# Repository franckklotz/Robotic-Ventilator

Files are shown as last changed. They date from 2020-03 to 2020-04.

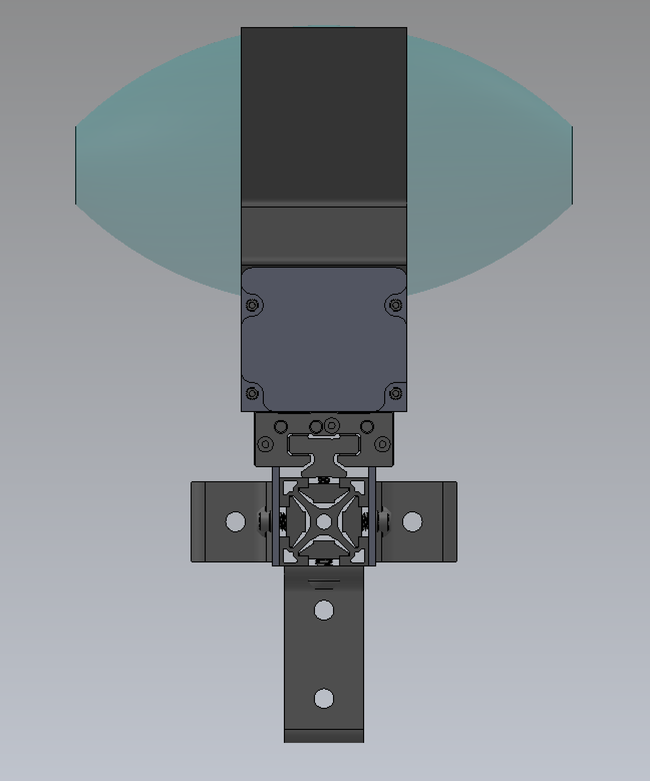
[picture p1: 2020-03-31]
3D rendering/Capture d’écran, le 2020-03-31 à 14.56.15.png

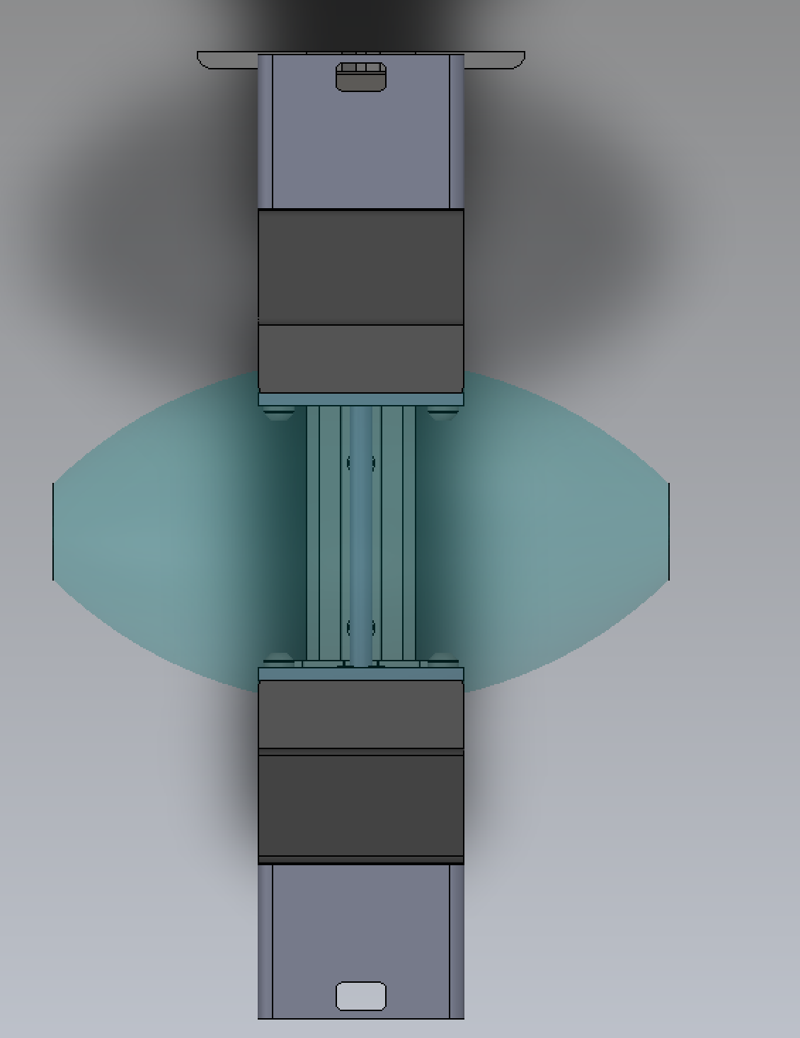
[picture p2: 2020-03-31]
3D rendering/Capture d’écran, le 2020-03-31 à 14.56.59.png

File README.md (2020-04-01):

# Project overview

Hello,

with key people in robotics design and Software development, a MD, and a MD Student, we decided to work on a Ventilator since the Covid-19 crisis.

Since we worked together in multiple indutrial robotic project, we called it Robotic repirator team.

We also participate to the https://www.agorize.com/en/challenges/code-life-challenge?lang=en as Robotic Team. this was a challenge to design a ventilator in a few days .

After few idea, we decided tu use an existing Manual Ventilator, AMBU ( see web site ) and control the flow using a stepper motor to precisely control air flow, volume, cylce per minute. The design can be adapted to similar AMBU compatible manual ventilator to "automate" the process of ventilating.

Thanks to Paulo Arruda and Patrick Schmitt to have "worked" some late night on brainstorming this idea / concept.

unfortunately, we could not get all parts to have a working prototype as per 31 march 2020, so we decided to share openly our idea so we can continu to build and improve around the community.

The Store Closed aroud us ( Montreal, Canada ), and delivery was jumping out of range for us to have a prototype for the 31 march 2020.

So please feel free to get inspired from this proposal and do not hesitate to improve.

do not hesitate to contact us via email for any specific questions.

# Specification

the specification are the folowing :

Pressure control up to 40 cmH2O, expiration pressure up to 25 cmH2O

Respiration ratio from 6 to 40 breath per minute

Adjustable inspiratiory time I:E ration

FiO2 from 21 to 100 % in 10 % increase 

Trigger time and or patient 

Connect to standard mask 

Dual Circuit with non rebreathing valve ( Y patient ) 

humidity and temperature not controlled in our design

O2 read out not in our design 

O2 sensor are very expensive and "impossible to find " @ end of march 2020

# Concept

concept 1  : ML, F and I:E adjustement via software, PEEP mechanical valve

Concept 1a : ML, F and I:E adjustement via software, PEEP mechanical valve, O2 adjustement based on template based on ML/F to adjust O2 volume. ( hospital have valve to adjust flow )

Concept 2  : ML, F and I:E adjustement via software, PEEP mechanical valve, but O2 adjustement via software using electrovalve that will be pulsed based on PWM in order ro mix Air / O2 ratio.

Concept 3  : ML, F and I:E adjustement via software, PEEP mechanical valve, but O2 adjustement via software using electrovalve that will be pulsed based on PWM in order ro mix Air / O2 ratio, and PEEP adjustement on a exhaust chamber based on solenoid valve to exhaust. Safety valve needs to be of course implemented.

please see document pdf for high level concept.

# Mechanical parts

The complete 3D parts and assembly is available in the specific folder. The different Ambu clone may have different dimentions but our intent is to design the claws in such way it will fit the different models destinated to support adults.
It was designed with Solidworks.

you can download a free viewer, edrawing to see the design.

the free viewer will allow you to hide parts ( like cover ) or make some parts transparent, and of course zoom in out, rotate and basic navigation around the mechanical design.

please open the AUTOMATIC AMBU ACTUATOR SYSTEM.SLDASM file to see the assembly.

PARTS :

All parts starting with a number, are https://www.mcmaster.com/ parts. You can oder parts directly from them or find equivalent parts.

Part 3D printed start with a 3D-xxxx. We have access to a 3D printer using ONYX plastic.

the main component is the stepper motor from https://www.pololu.com/product/2689 , this one is provided with the screw ( selected in design for speed of delivery reason ) but you could buy the same motor and adapt your own screw with this motor https://www.pololu.com/product/2267

the motor is sized for 60 respiration per minute, see the calculation excel for sizing.

# Electronic parts

the electronic is designed to have a main microprocessor, based on arduino or particle.io.

Arduino is well available, but the particle board have the capacity to update remotely. ( a plus during development, but a risk once running with real patient ).

the arduino selected was https://www.pololu.com/product/2188

The microprocessor board drives a 4988 stepper motor driver https://www.pololu.com/product/1182 that is controlled usind 2 pin, direction, and pulse for "speed" . This pulse needs to be managed to reach setup speed from medic team, and can also be managed to have "S" curve for inspiration and expiration.

of course, stepper motor needs to have a "zero" this could be achieved by "returning" the motor to zero and have it "mechanically" stopped, or adding a sensor for position zero and monitor this position "zero" for each positive pressure to patient. The flexibility can only by achieved using a Stepper motor.

To improve a little bit more the system, and to have the pressure setup, we wanted to use Athmospheric pressure monitor based on the bosch 280 https://www.adafruit.com/product/2652 . this will allow us to compare ambiant pressure with pressure to AMBU exhaust and manage the stepper motor accordingly, using a PID loop . ( also, with bypass to ensure minimum respiration setup by DRs )

These sensors would have beed used in the output of AMBU, the return from patient to monitor the PEEP pressure ( from 5 to 20 as standard PEEP pressure ), even if we wanted to use existing PEEP valve from AMBU.

This Pressure sensor was also used to monitor patient respiration, in order to do "Assisted Ventilation", and of course have a software to ensure minimum respiration per minute as per standard ventilator.

The precison expected using BOSCH 280 athmospherique sensor was, based on the position in the curve , from 5 to 10 %, that was the acceptable precision range for the challenge.

Once we will get all sensors, we will also test and validate theorie.

Off course, these sensor do not meet the "cleaning" requirement, but this could be changed, and we will mount them in a remote small chanber connected to the main "chambers" to avoid contamination, but this is not ideal.

# Other electric parts

Of course we need to have a power-supply 120-240 to 12 Volts, a Battery charger to charge a battery and keep electricity for 3 hours as per requirement, but this is more "off the shelf " equipment.

We need to finalize electric consumption to size battery.

We should also add Bright LED light and Buzzer to "alarm" medical team .

Again, this is considered standard equipment, from multiple vendor and we did not concentrate theses points.

# UI / UX interface 

to have a User Experience, User Interface able to replicate what the medical team is used, we selected 2 option. 

1 - using a 7.00 inch touch screen
2 - using a smaller 3.2 inch touch screen to save cost and have more availability 

the 7.00 screen is https://www.robotshop.com/ca/fr/affichage-lcd-tactile-7-nextion-hmi.html from Nextion

the 3.20 screen is https://www.robotshop.com/ca/fr/affichage-lcd-tactile-hmi-32-nextion.html also from Nextion

this system is for rapid deveolpement and provide a free "HMI" intreface, and also all code to interface to Arduino and other microprocessor board.

you can download the software to design HMI from nextion at https://nextion.tech/

there is also a cheaper version from China, but not available outside of China.

The 7.00 inch screen is able to draw curve, so we will be able to replicate UI used in actual Ventilator.

# Final case / Box

final concept including a complex box and support for the HMI LCD screen is not finalized, and need to be completed.

this was not our top priority and is "easy" to do once all tests are done.

# Software 

Software wa in a few steps, of course we started with a POC, proof of concept, and evolve to a pre-releae.

- POC : control motor based on "parameter from console" Volume is controlled by Servo 
- STEP 01 : ensure sensor "zero" is activated and create alarm 
- STEP 02 : change cycle per minute based on "parameter from console :
- STEP 03 : change ratio push, release air ( ratio 1/4 to 3/4 ) based on parameter fom console
- STEP 04 : read pressure from multiple sensor and determine pressure from 0 - to - 60 mm
- STEP 05 : add PID control loop based on Pressure sensor 
- STEP 06 : add alarm for multiple alarms as per specification
- STEP 07 : start HMI screen with +/- for Fio2 VT F ration 
- STEP 08 : test functions and integration of HMI 
- STEP 09 : calibration procedure to enter data via HMI
- STEP 10 : burn out and validation of AMBU durability.

- Prerelease once all steps are done and running 24/7 .

# Calibration

the calibration has to be performed using the https://www.mcmaster.com/4125K21 pressure readout.
Calibration would be done and entered via HMI before shipment.

Of course, a calibration method using "water tube" to measure pressure should also be provided to allow calibration using "basic" equipment.

# Cleaning 

cleaning procedure is based on the AMBU procedure.
If sensor used for Athmospheric pressure, cleaning shoud consider "replacing sensor" since cost is low, particularly if sourcing direct sensor in high volume from BOSCH or key supplier.

# follow up

if you are interrested of this concept using stepper motor, pid, hmi , please do not hesitate to contact us.

we are still continuing to go ahead, even if the 31 march dead line is .... dead .

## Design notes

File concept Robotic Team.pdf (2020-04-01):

# Robotic Ventilator

# Franck Klotz Paulo Arruda Patrick Schmitt

# Concept 1

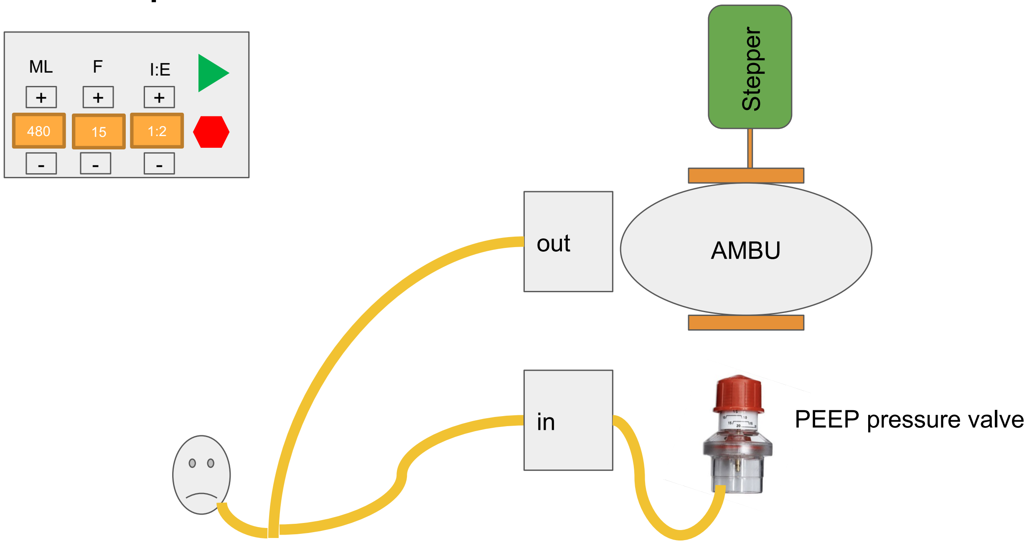
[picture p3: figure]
out; Stepper; AMBU; PEEP pressure valve

# Concept 1a

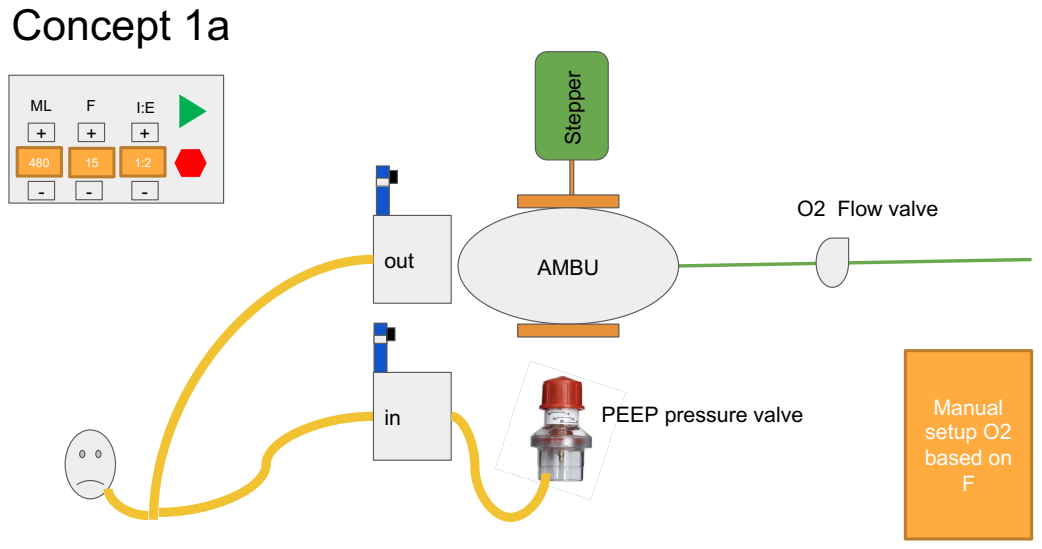
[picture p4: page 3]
out; Stepper; AMBU; O2 Flow valve; Manual setup O2 based on F

PEEP pressure valve

# Concept 2 -

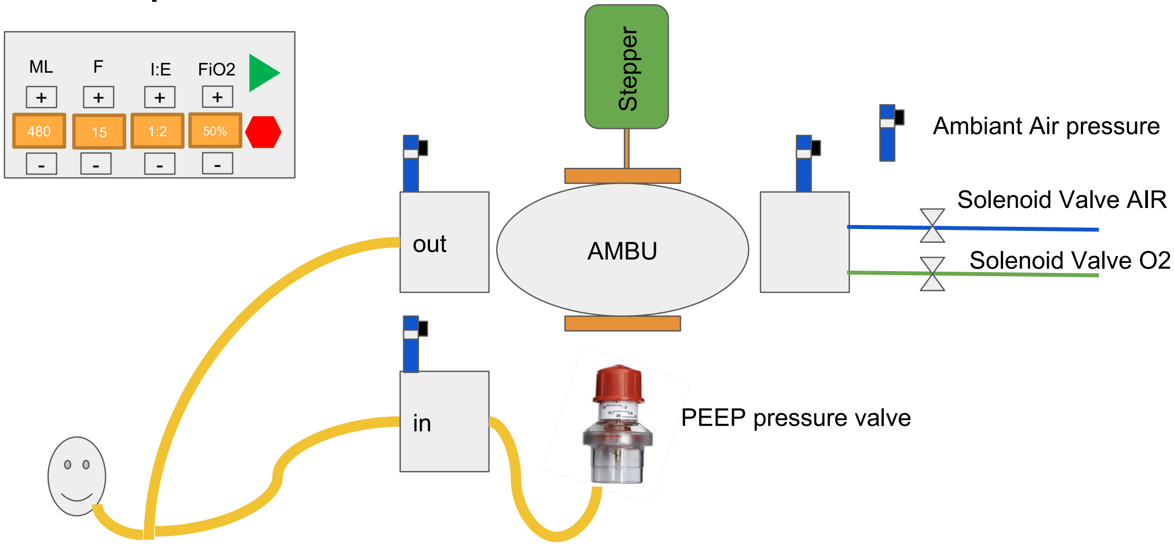
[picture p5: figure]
out; Stepper; Ambiant Air pressure; AMBU; PEEP pressure valve; Solenoid Valve AIR; Solenoid Valve O2; FiO2

# Concept 3

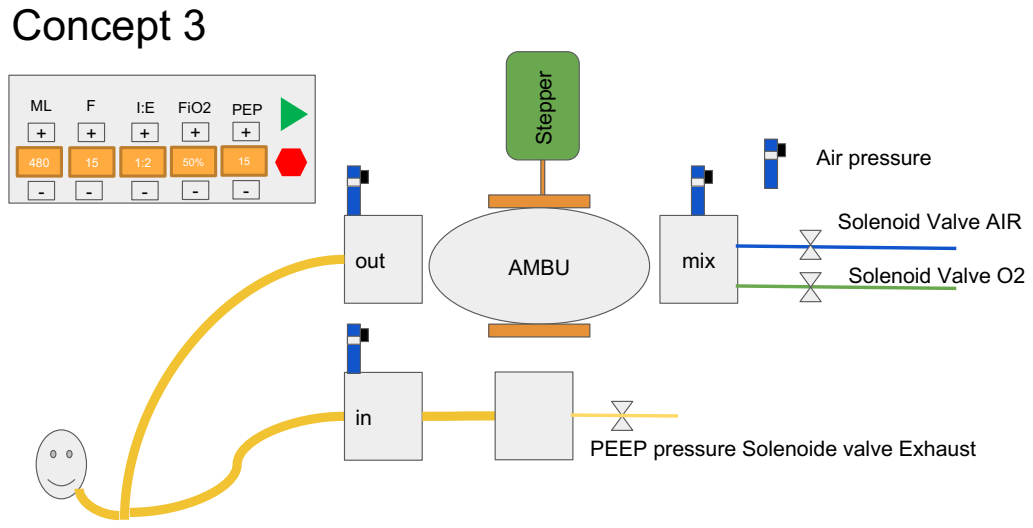
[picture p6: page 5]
out; mix; Stepper; Air pressure; AMBU; Solenoid Valve O2; FiO2; PEP

Solenoid Valve AIR

PEEP pressure Solenoide valve Exhaust

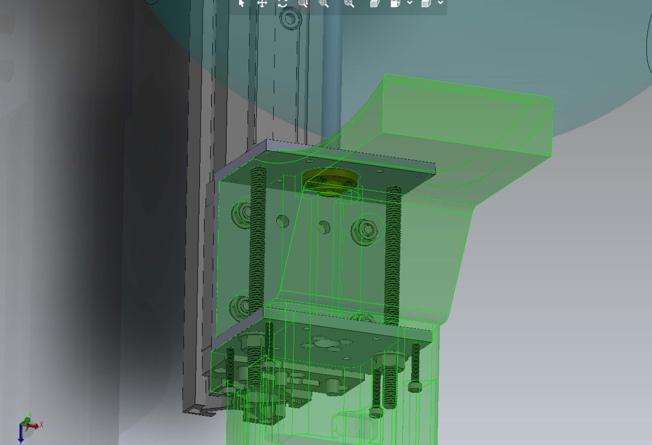
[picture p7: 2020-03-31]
3D rendering/Capture d’écran, le 2020-03-31 à 15.01.20.png

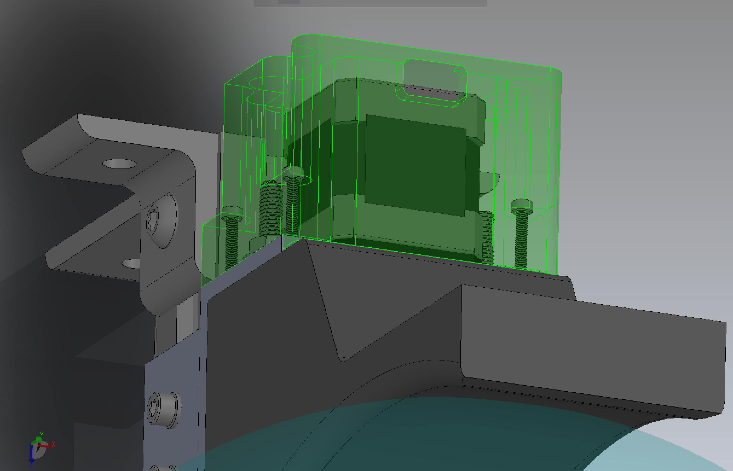
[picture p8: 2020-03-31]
3D rendering/Capture d’écran, le 2020-03-31 à 15.00.11.png

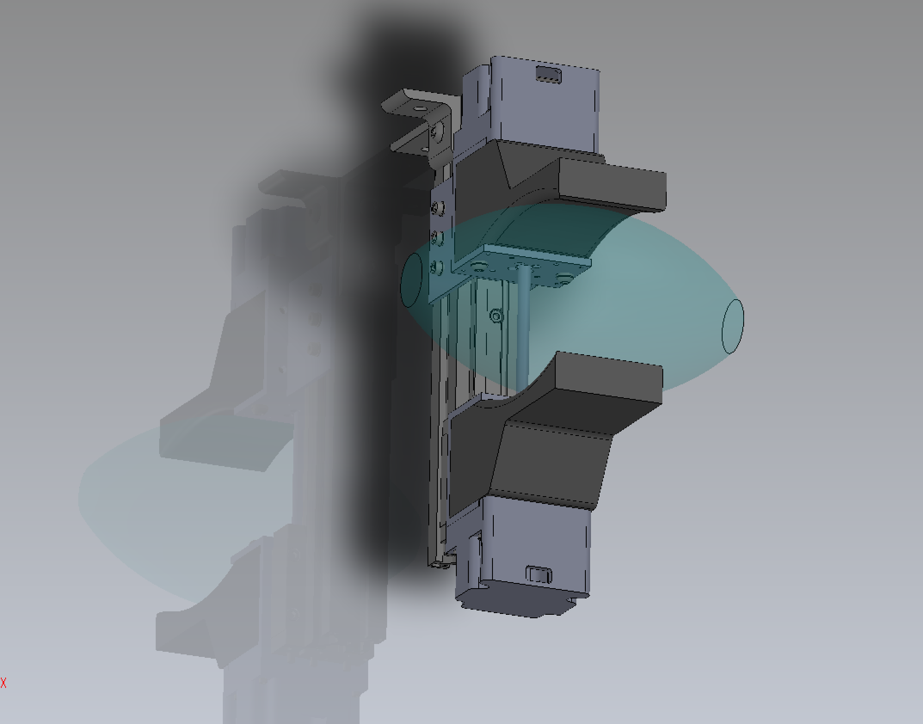
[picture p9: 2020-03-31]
3D rendering/Capture d’écran, le 2020-03-31 à 14.58.05.png

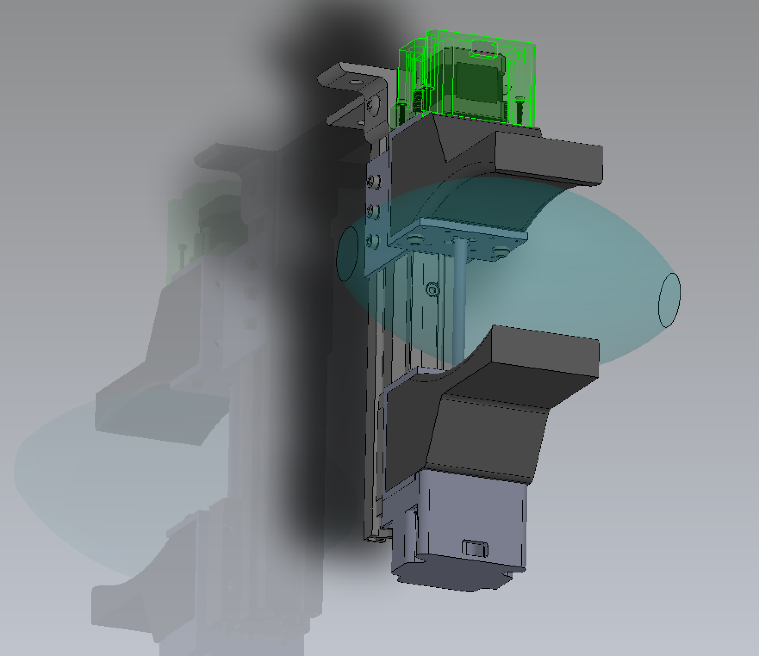
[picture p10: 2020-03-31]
3D rendering/Capture d’écran, le 2020-03-31 à 14.59.43.png

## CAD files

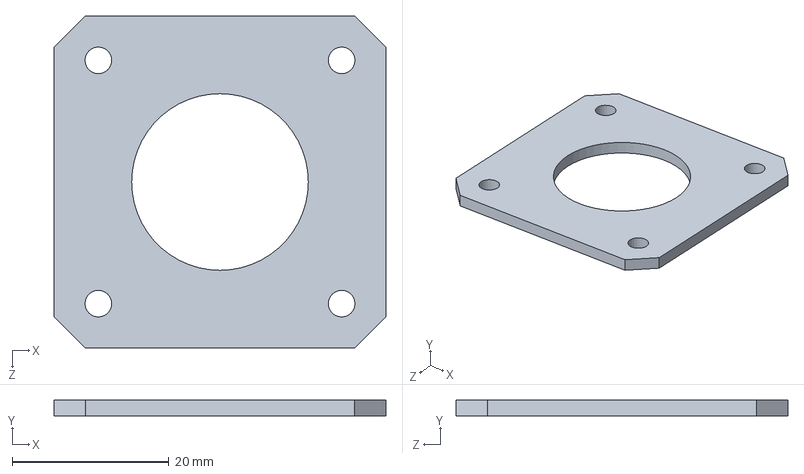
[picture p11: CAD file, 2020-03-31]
mechanical parts/3D-PRINTED - SPACER NEMA 17.SLDPRT
42.3 x 2.00 x 42.3 mm

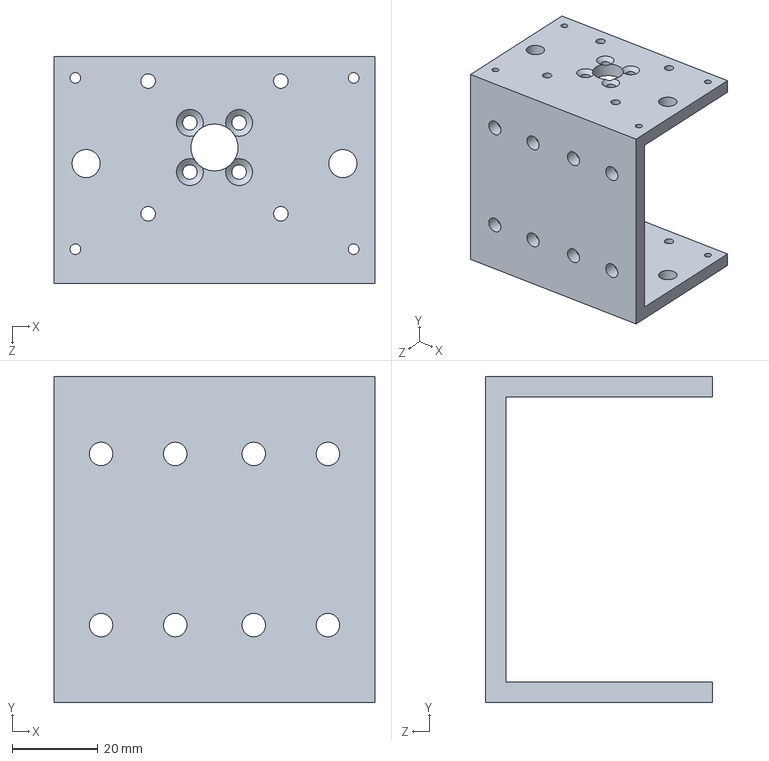
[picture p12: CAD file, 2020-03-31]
mechanical parts/MACHINED BRACKET - FIX GRIPPER.SLDPRT
75.0 x 76.2 x 53.0 mm

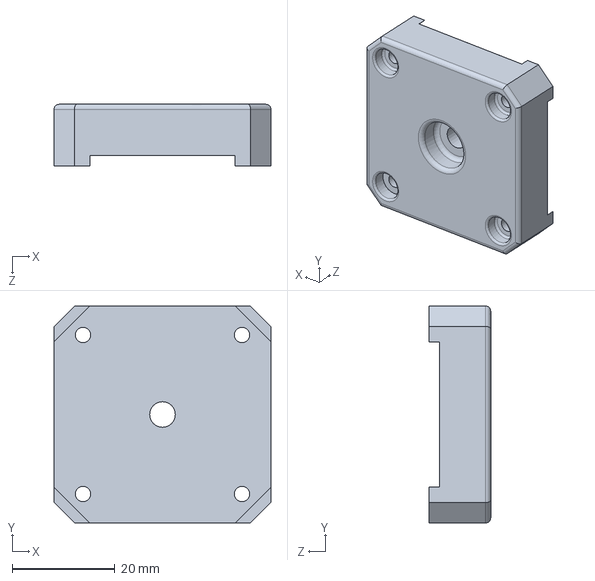
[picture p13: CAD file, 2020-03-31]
mechanical parts/Base.SLDPRT
42.3 x 42.3 x 12.0 mm

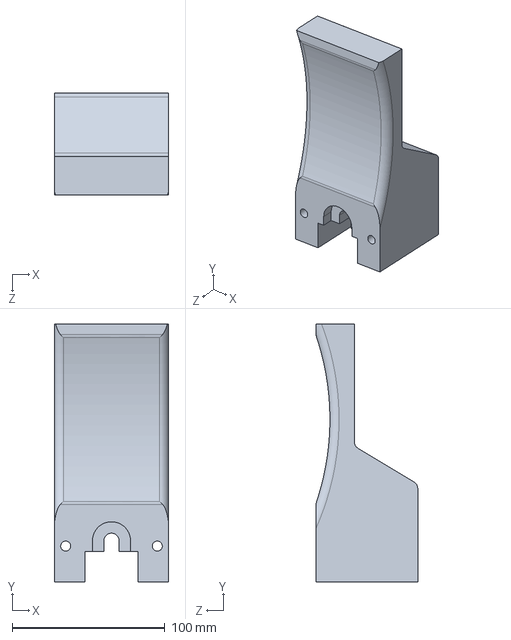
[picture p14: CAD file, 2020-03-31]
mechanical parts/3D-PRINTED - GRIPPER.SLDPRT
75.0 x 169.0 x 66.6 mm

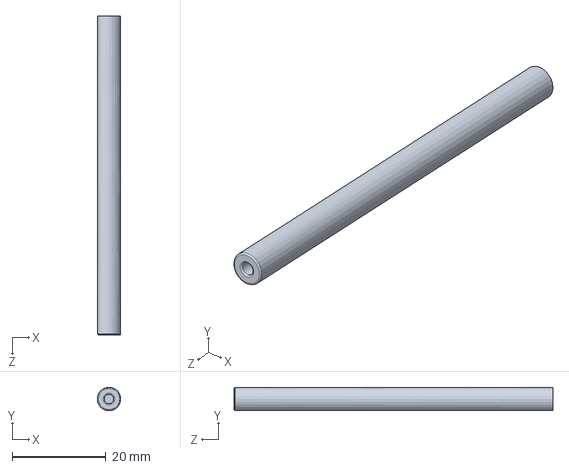
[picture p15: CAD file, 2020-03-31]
mechanical parts/Eje.SLDPRT
5.00 x 5.00 x 68.0 mm

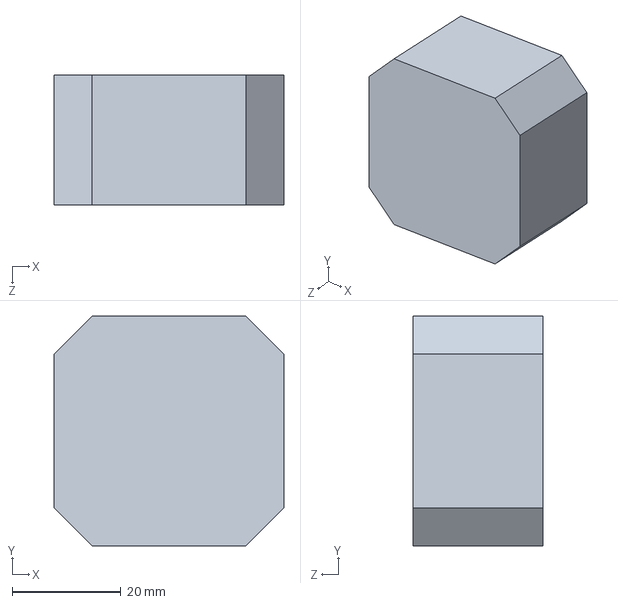
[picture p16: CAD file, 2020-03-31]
mechanical parts/Cuerpo.SLDPRT
42.3 x 42.3 x 24.0 mm

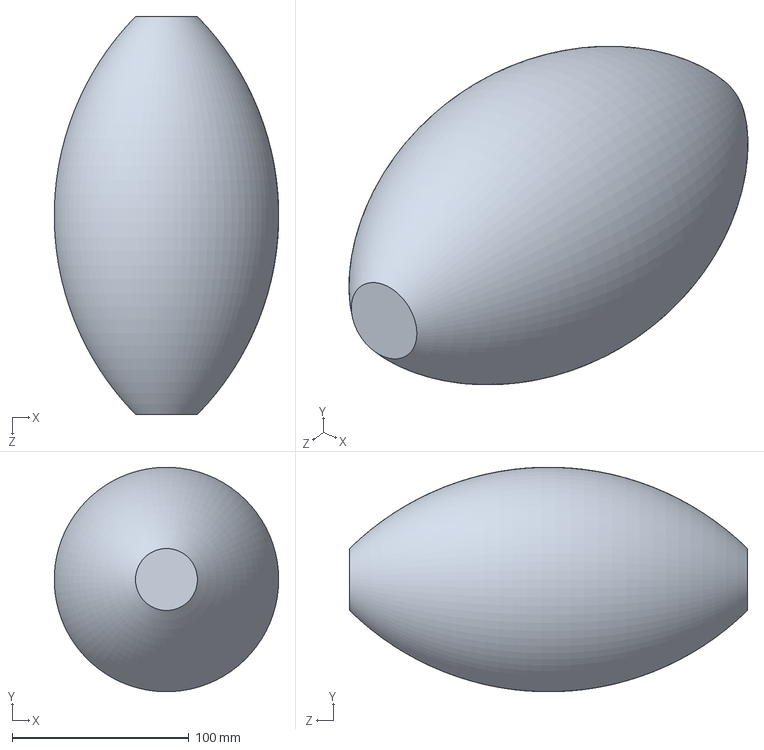
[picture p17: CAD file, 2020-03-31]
mechanical parts/ENV - APPROX SIZE AMBU BAG.SLDPRT
126.8 x 126.9 x 225.0 mm

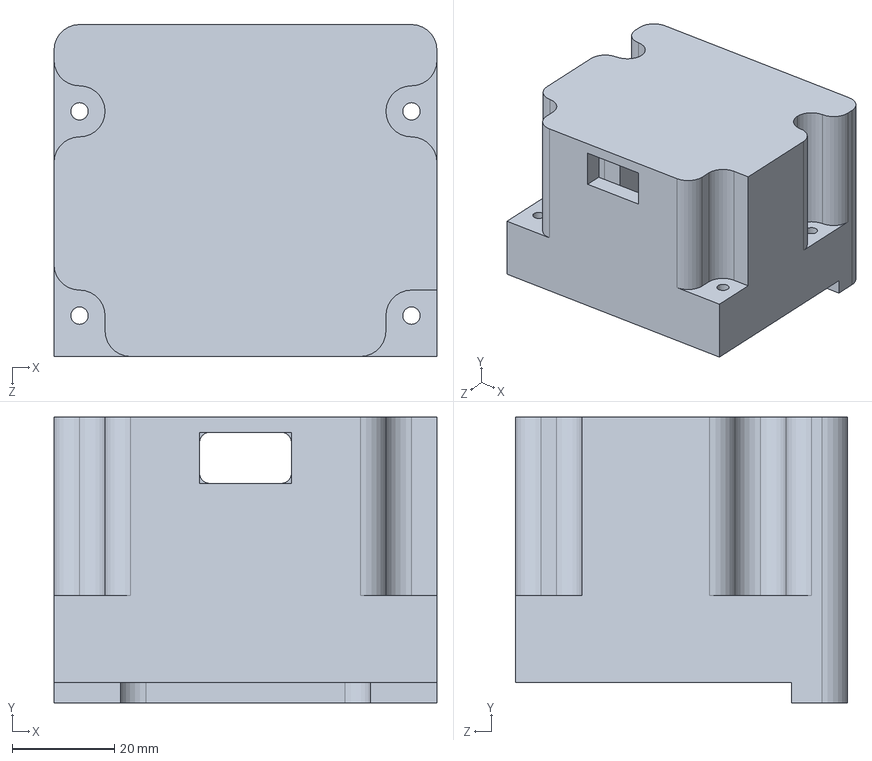
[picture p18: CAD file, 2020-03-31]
mechanical parts/3D-PRINTED - CAP.SLDPRT
75.0 x 56.0 x 65.0 mm

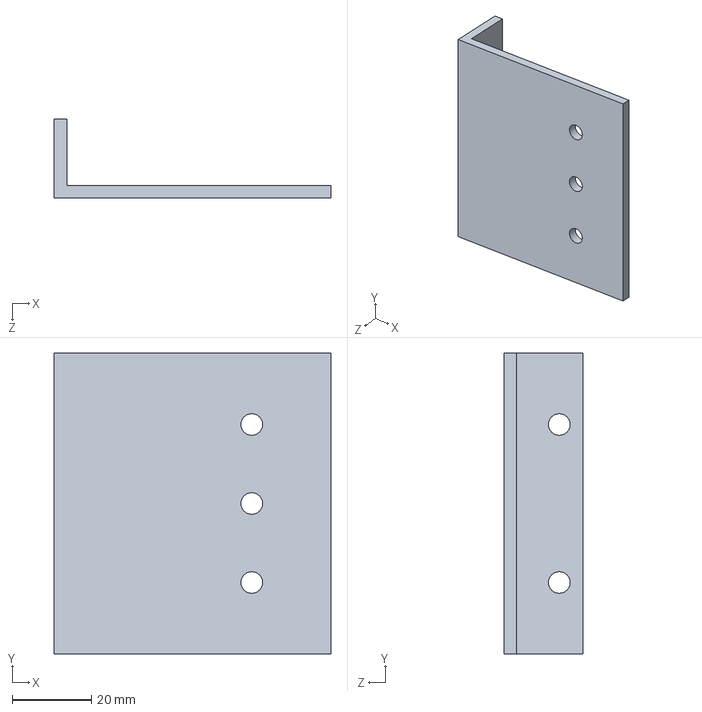
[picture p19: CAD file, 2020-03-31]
mechanical parts/MACHINED BRACKET - FIX BOTTOM GRIPPER TO ALUM EXTRUSION.SLDPRT
70.0 x 76.2 x 20.0 mm

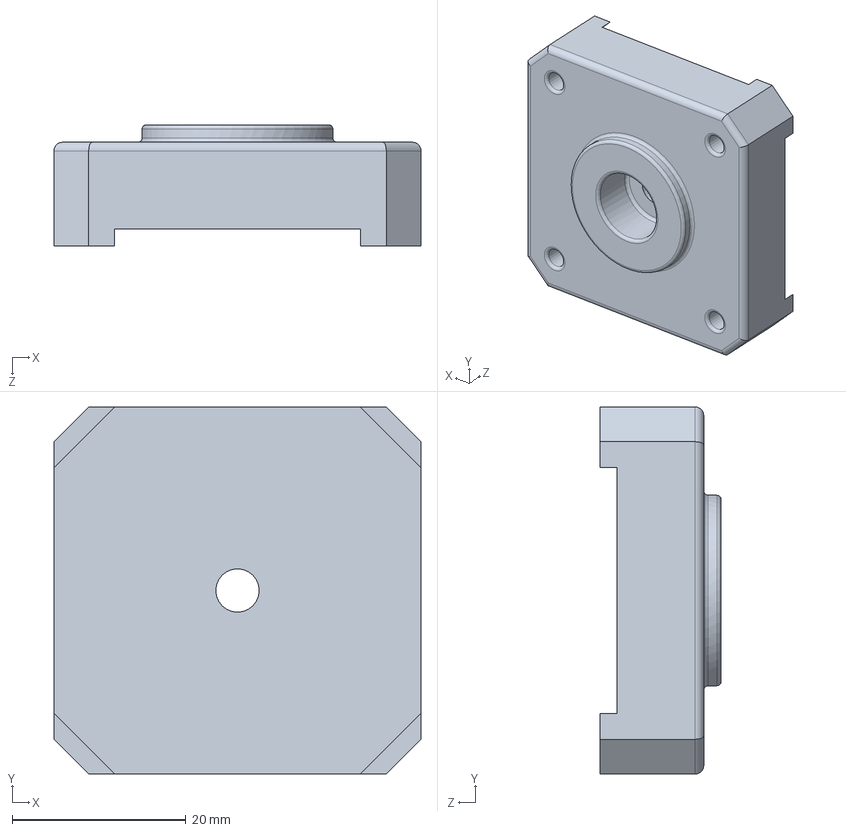
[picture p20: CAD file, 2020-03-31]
mechanical parts/Tapa.SLDPRT
42.3 x 42.3 x 14.0 mm

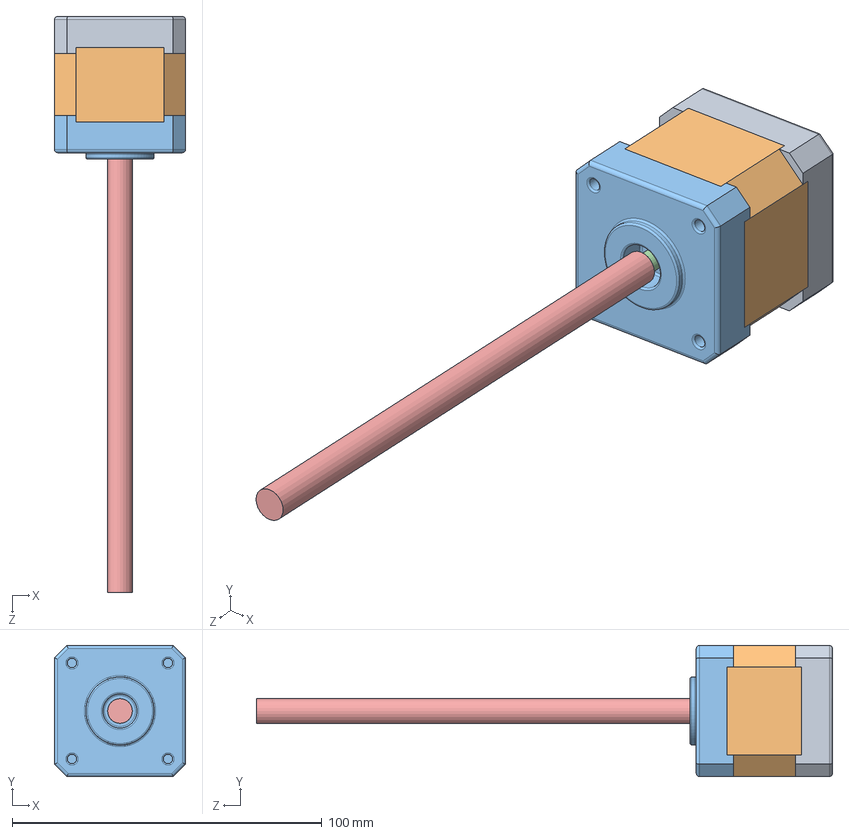
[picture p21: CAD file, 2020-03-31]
mechanical parts/POLOLU 2689 - NEMA 17 WITH BALL SCREW.SLDASM
42.3 x 42.3 x 186.0 mm
Base
Cuerpo
Tapa
Eje
Lead Screw

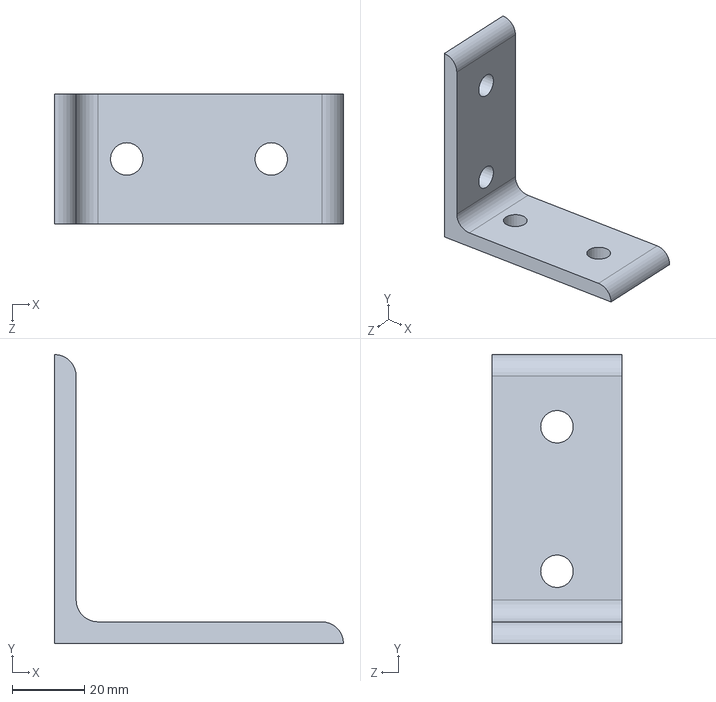
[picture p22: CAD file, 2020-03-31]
mechanical parts/5537T347_ALUMINUM T-SLOTTED FRAMING EXTRUSION.SLDPRT
80.0 x 80.0 x 36.0 mm

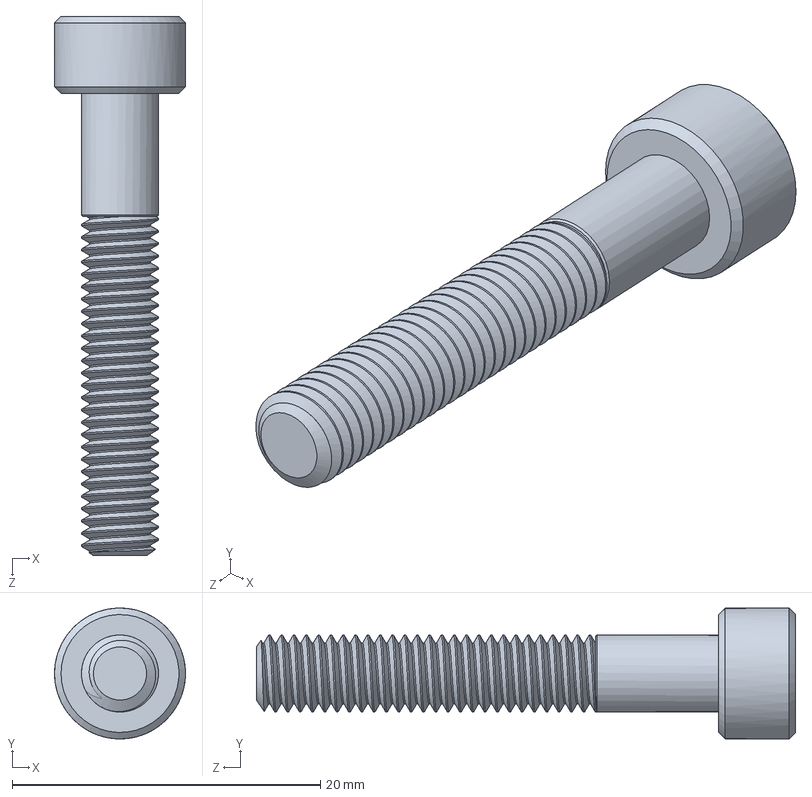
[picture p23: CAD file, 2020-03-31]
mechanical parts/91292A192_TYPE 18-8 SS SOCKET HEAD CAP SCREW.SLDPRT
8.50 x 8.49 x 35.0 mm

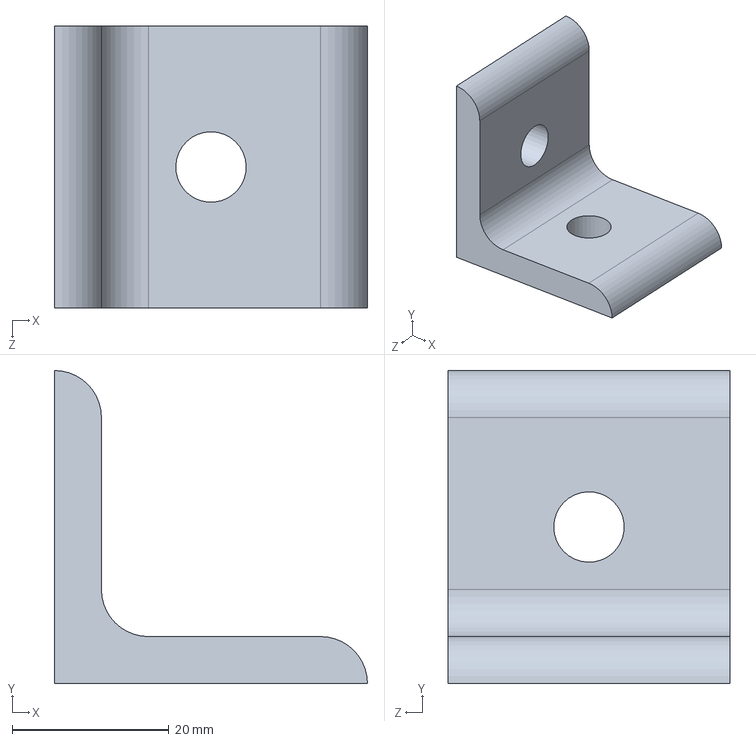
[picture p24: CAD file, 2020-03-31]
mechanical parts/5537T937_ALUMINUM T-SLOTTED FRAMING EXTRUSION.SLDPRT
40.0 x 40.0 x 36.0 mm

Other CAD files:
mechanical parts/ALUMINUM EXTRUSION HARDWARE - ROBOUNITS-TIN-4508 - M8 NUT.sldprt
mechanical parts/92095A129_BUTTON HEAD HEX DRIVE SCREW.SLDPRT
mechanical parts/ENV - NUT LEAD SCREW POLOLU 2688.SLDPRT
mechanical parts/92290A867_SUPER-CORROSION-RST 316 SS SCKT HEAD SCREW.SLDPRT
mechanical parts/91292A060_TYPE 18-8 SS SOCKET HEAD CAP SCREW.SLDPRT
mechanical parts/91292A123_TYPE 18-8 SS SOCKET HEAD CAP SCREW.SLDPRT
mechanical parts/92095A492_BUTTON HEAD HEX DRIVE SCREW.SLDPRT
mechanical parts/92125A130_TYPE 18-8 SS FLAT-HEAD SOCKET CAP SCREW.SLDPRT
mechanical parts/97400A101_TYPE 18-8 SS SERRATED-FLANGE LOCKNUT.SLDPRT
mechanical parts/97400A858_18-8 STAINLESS STEEL SERRATED FLANGE LOCKNUT (1).SLDPRT
mechanical parts/97400A858_18-8 STAINLESS STEEL SERRATED FLANGE LOCKNUT.SLDPRT
mechanical parts/9867K134_SLEEVE BEARING CARRIAGE.SLDPRT
mechanical parts/9867K300_SLEEVE BEARING CARRIAGE.SLDPRT
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
